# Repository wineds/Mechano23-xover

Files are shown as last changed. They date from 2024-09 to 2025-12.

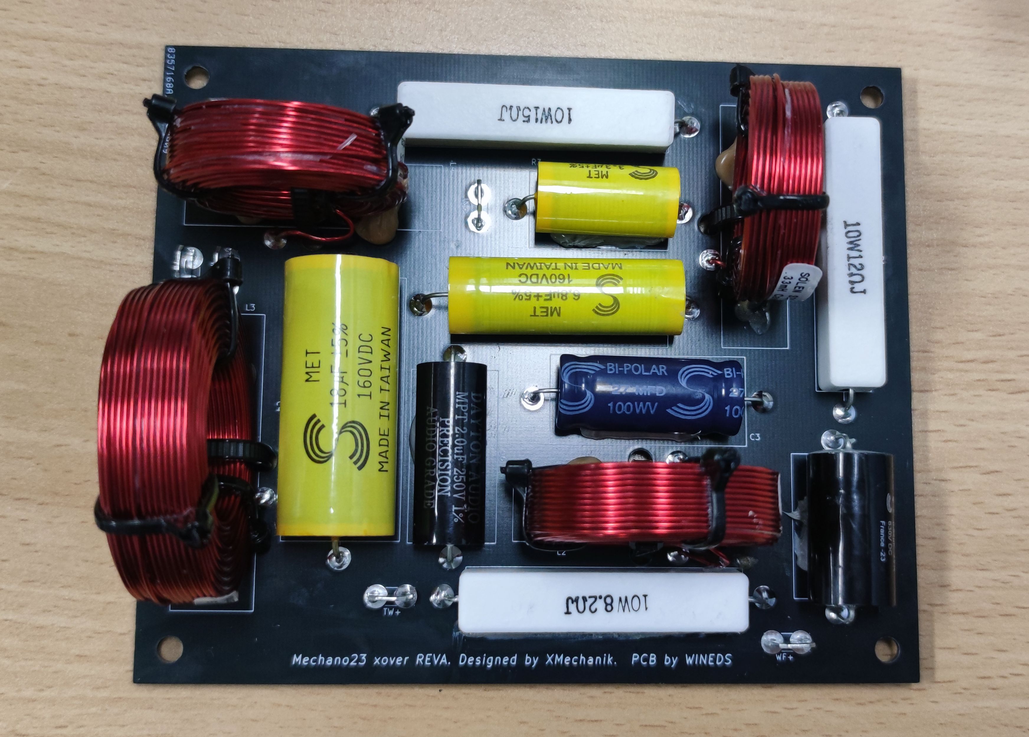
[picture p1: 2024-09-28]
1726199938259.jpg

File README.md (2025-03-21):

Manufacturing files for Mechano23 xover PCB.  The RAR file needs to be uploaded to the PCB vendor (eg: JLCPCB or PCBWAY etc).

How to order from JLCPCB :

https://jlcpcb.com/help/article/How-do-I-place-an-order

NB : Use the "Add Gerber files" button to upload (mechano23_revA_plots.rar) RAR file.

BOM is as per component links in the first post of the ASR review here : https://www.audiosciencereview.com/forum/index.php?threads/mechano23-open-source-diy-speaker-review.54066/

Alternatively see simple BOM here : mechano23_xover_schematic.xls

6.3mm PCB lugs are as per H2094.pdf from local electronics store (5mm pitch, 1.2mm pin)  These would fit : https://www.newark.com/ettinger/19-68-041/terminal-pc-quick-fit-1-1mm/dp/10AC9921 (1.1mm pin)

Closest mouser alternative I could find is : https://au.mouser.com/ProductDetail/TE-Connectivity-AMP/725964-2?qs=qCxwlXJ4fnwpPO7DZFi5oQ%3D%3D  Pins are 1.3mm in this case but should push into PCB holes with some gentle persuasion.  Could also try these : https://www.newark.com/multicomp-pro/pc250-836lt/terminal-tab-6-35mm-solder-uninsulated/dp/05R7934 (cheaper but also 1.3mm pin))

For inductors I used "Liquid Nails" and cable ties ("knot" on component side) to secure them to the PCB.  For all other parts a neutral cure silcone was used to ensure parts don't rattle and buzz on PCB.  Cable tie holes are 4mm.

PCB mounting holes are 4.3mm.  

**IMPORTANT - The inductor leads are coated with enamel.  You will need to scrape/sand the ends of the leads to remove the enamel before soldering.  A hobby knife and/or sandpaper can be used for this purpose.




mechano23_xover_schematic

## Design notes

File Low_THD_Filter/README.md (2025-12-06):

Low Distortion Filter for Mechano23.

The filter needs to be placed in series with the woofer (either positive or negative terminal).

PCB lugs are the same as crossover PCB.

low_THD_filter_PCB





If you use the dayton 0.13mH inductor remove the cable tie furthest from the termination point and carefully start removing outer windings until only 4 remain.  This will result in a 0.11mH inductor.  Complete by adding a few new cable ties to aid mechancial stability.  I also applied some "liquid nails" to help keep the windings in place. viz:





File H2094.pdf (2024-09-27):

## Accessory ／ PCB Terminal

P-850

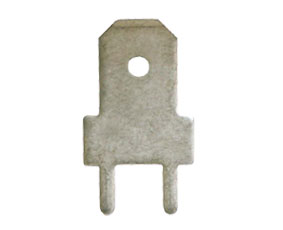
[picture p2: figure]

Material | Brass, Tin plated
Screw
Current Rating | 30A

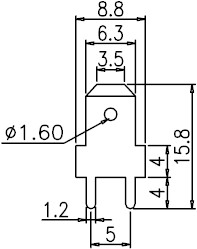
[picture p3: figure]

TEL: +886-2-2908-0614 | FAX: +886-2-2908-8549 | E-mail: infor@dinkle.com.tw

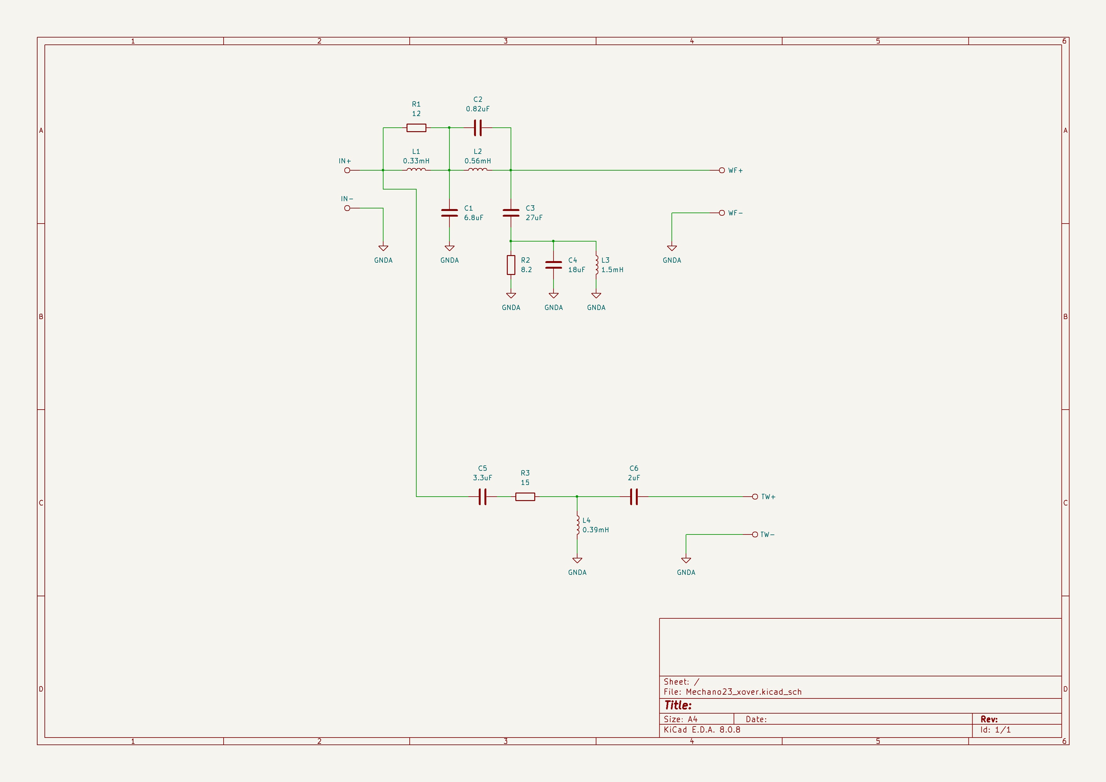
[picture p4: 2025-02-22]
mechano23_xover_schematic.jpg

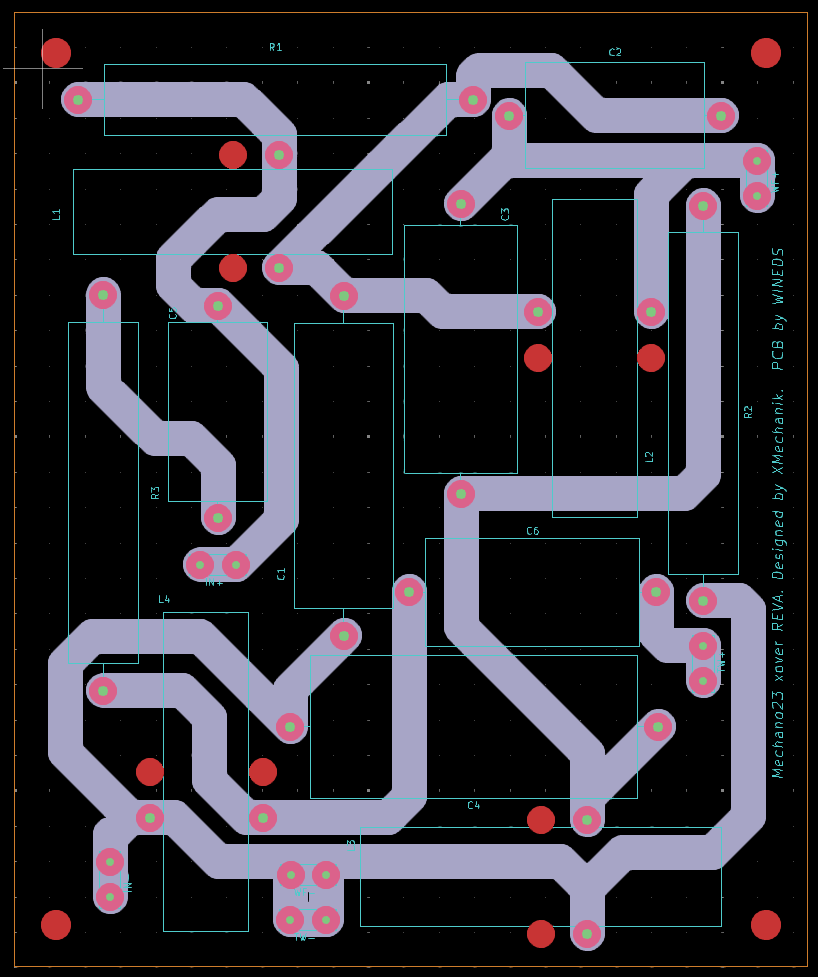
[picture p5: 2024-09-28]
Screenshot 2024-09-09 180137.png

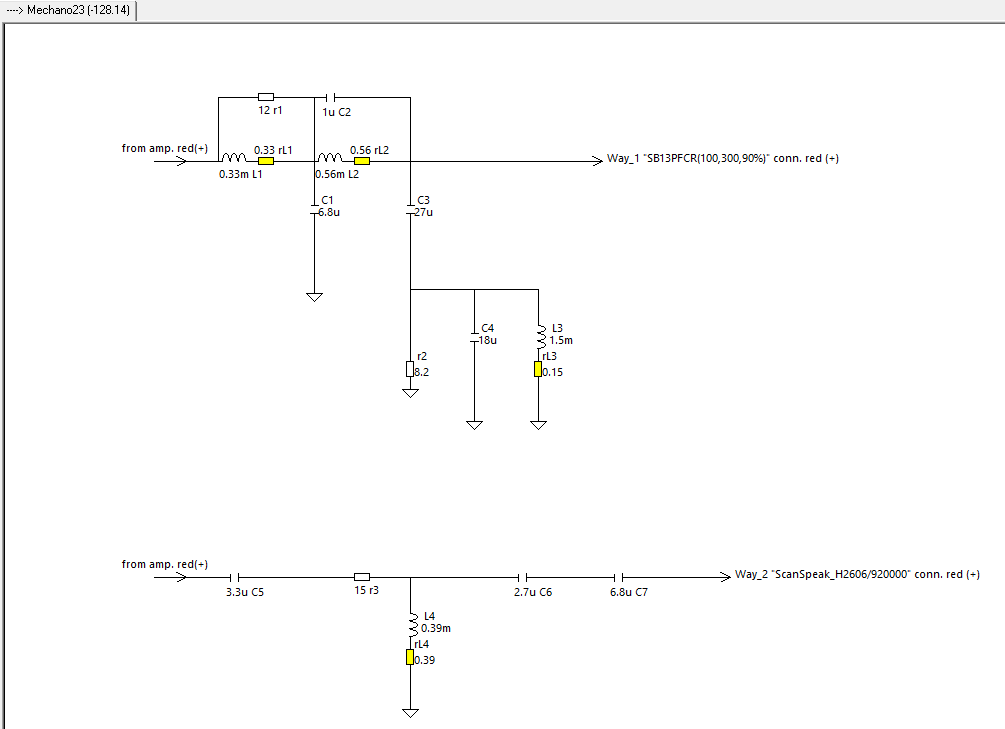
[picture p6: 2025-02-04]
schemat.png

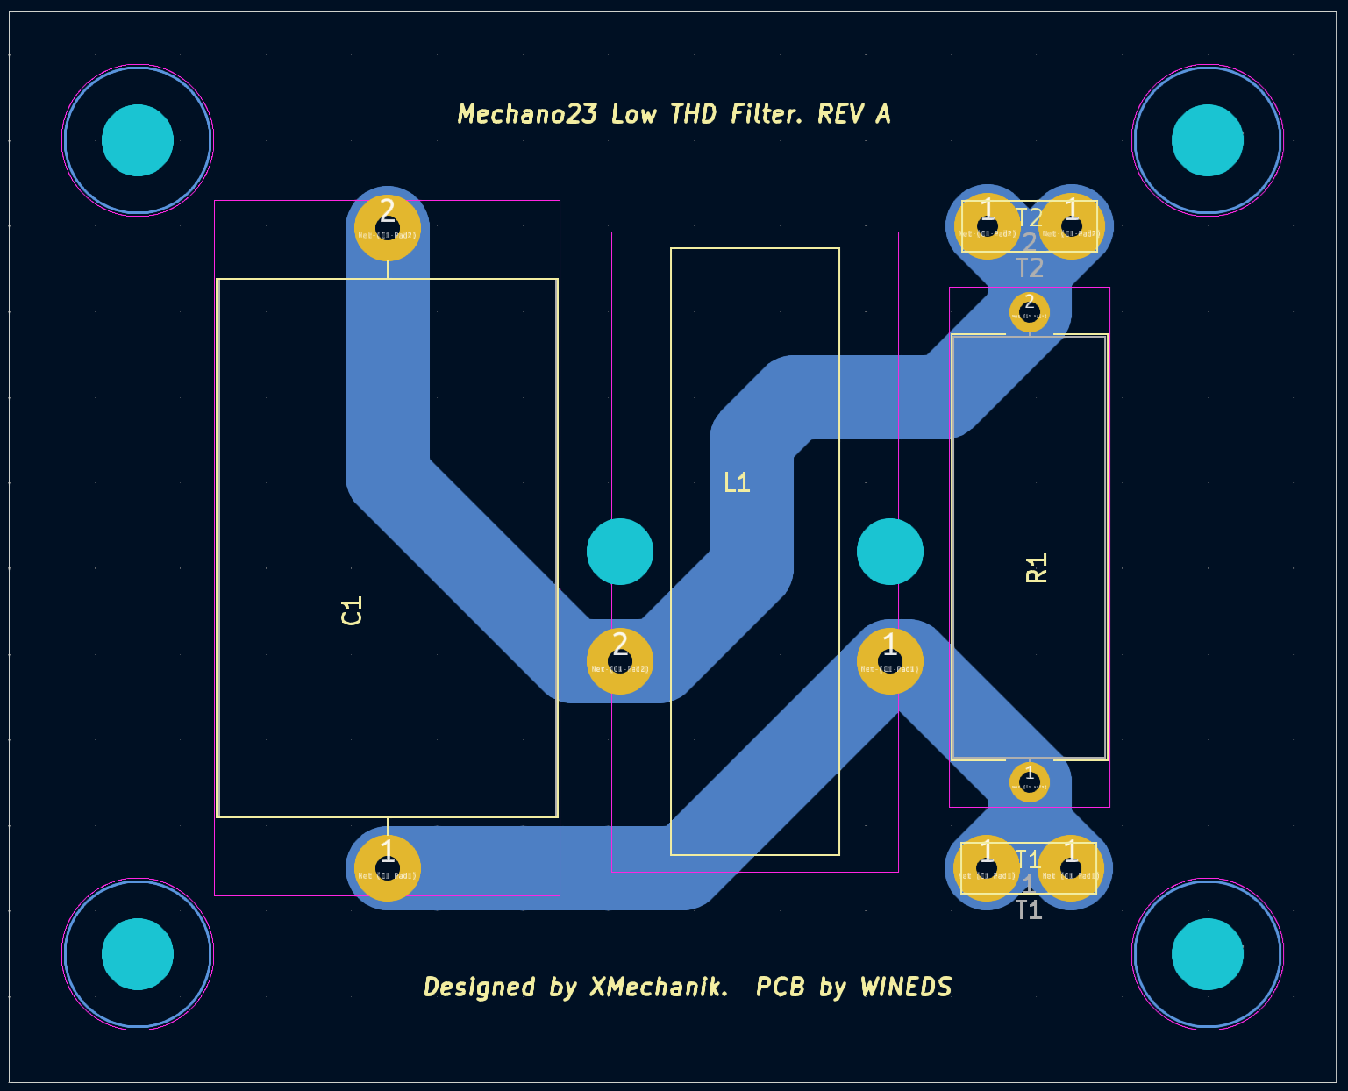
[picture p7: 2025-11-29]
Low_THD_Filter/low_THD_filter_PCB.png

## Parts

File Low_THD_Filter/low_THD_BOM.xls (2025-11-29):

Ref | Value | Supplier | Notes
L1 | 0.11mH | https://www.solen.ca/en/products/solen-perfect-lay-air-core-inductors-s18_11-0_11mh-18awg-inductor
 |  | https://jantzen-audio.com/?s=000-0266
 |  | https://www.daytonaudio.com/product/1320/lw18-13-0-13mh-18-awg-perfect-layer-inductor | Unwind all but 4 outer windings to make 0.11mH
C1 | 4.7uF | https://www.daytonaudio.com/product/187/pmpc-4-7-4-7uf-250v-precision-audio-capacitor
 | Optional see: | https://www.audiosciencereview.com/forum/index.php
R1 | 47ohm >=0.25w | https://jantzen-audio.com/?s=002-0364 | A generic metal film resistor >= 0.25W can also be used

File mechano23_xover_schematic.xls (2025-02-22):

Ref | Value | Supplier
L1 | 0.33mH | Ind. 0.33mH link CA$5.10 (https://www.solen.ca/en/products/solen-perfect-lay-air-core-inductors-s20_33-0_33mh-20awg-inductor)
L2 | 0.56mH | Ind. 0.56mH link CA$6.73 (https://www.solen.ca/en/products/solen-perfect-lay-air-core-inductors-s20_56-0_56mh-20awg-inductor)
L3 | 1.5mH | Ind. 1.5mH link CA$10.58 (https://www.solen.ca/en/products/solen-perfect-lay-air-core-inductors-s201_5-1_5mh-20awg-inductor)
L4 | 0.39mH | Ind. 0.39mH link CA$5.81 (https://www.solen.ca/en/products/solen-perfect-lay-air-core-inductors-s20_39-0_39mh-20awg-inductor)
R1 | 12ohm | Res. 12ohm link CA$0.41 (https://www.solen.ca/en/products/solen-cement-type-wirewound-resistors-wwsqp10j12r-12ohm-10watt-resistor)
R2 | 8.2ohm | Res. 8.2ohm link CA$0.41
R3 | 15ohm | Res. 15ohm link CA$0.41 (https://www.solen.ca/en/products/solen-cement-type-wirewound-resistors-wwsqp10j15r-15ohm-10watt-resistor)
C1 | 6.8uF | Cap. 6.8uF link CA$2.39 (https://www.solen.ca/en/products/solen-polyester-capacitors-pemt160j685-6_8uf-160v-metallized-polyester-film)
C2 | 0.82uF | Cap. 0.82uF link CA$6.09 (https://www.solen.ca/en/products/solen-fast-capacitors-ppe082-0_82uf-630v-metallized-polypropylene-film)
C3 | 27uF | Cap. 27uF link CA$1.73 (https://www.solen.ca/en/products/solen-non-polarized-electrolytic-capacitors-b05a100k276-27uf-100v)
C4 | 18uF | Cap. 18uF link CA$6.39 (https://www.solen.ca/en/products/solen-polyester-capacitors-pemt160j186-18uf-160v-metallized-polyester-film)
C5 | 3.3uF | Cap. 3.3uF link CA$1.41 (https://www.solen.ca/en/products/solen-polyester-capacitors-pemt160j335-3_3uf-160v-metallized-polyester-film)
C6 | 2uF | Cap. 2.0uF link CA$2.48 (https://www.solen.ca/en/products/dmpc-2-0)

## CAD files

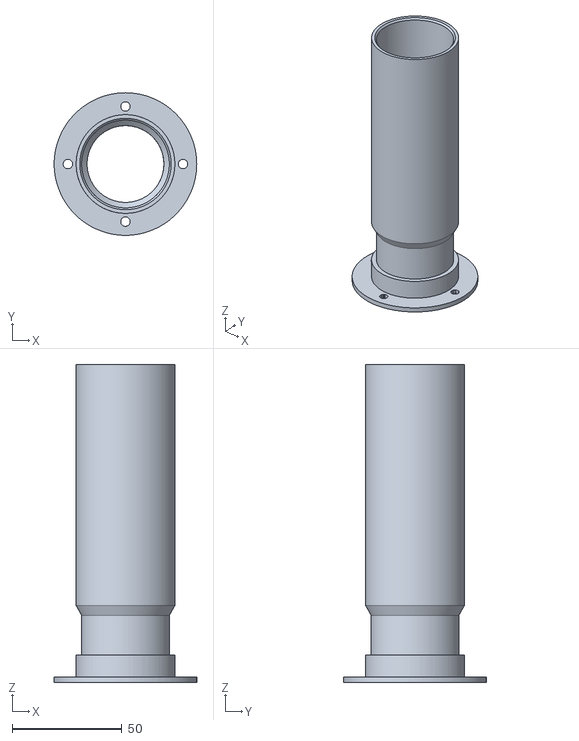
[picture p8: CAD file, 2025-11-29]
3D Printable port/Mechano23_port_rev6.stl
65.0 x 65.0 x 145.0

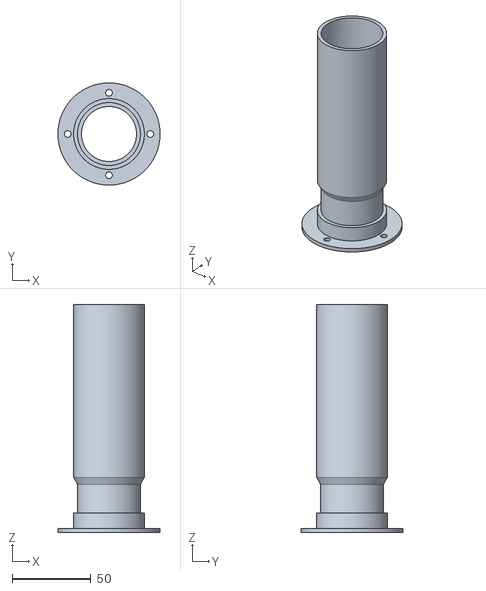
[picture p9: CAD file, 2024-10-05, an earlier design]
3D Printable port/Mechano23_port_rev4.stl
65.0 x 65.0 x 145.0

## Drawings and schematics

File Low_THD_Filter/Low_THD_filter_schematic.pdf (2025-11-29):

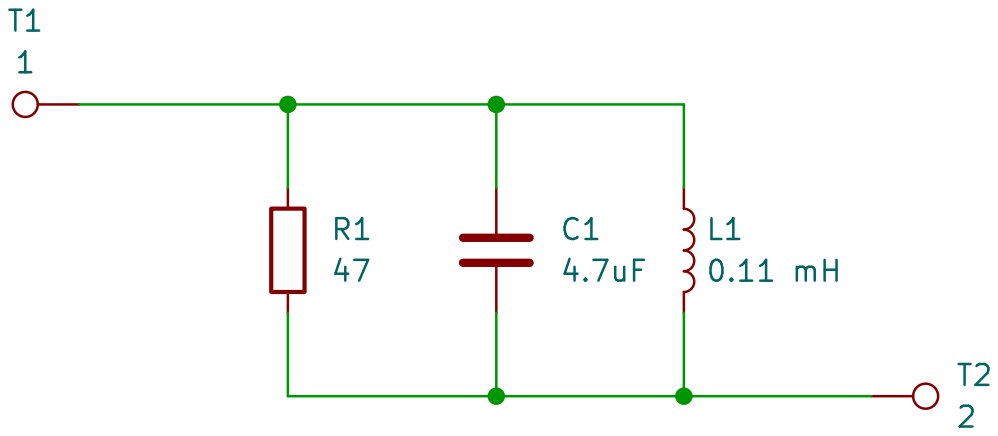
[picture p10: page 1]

Id: 1/1 Title: File: Low_THD_bass_trap.kicad_sch Sheet: / C1

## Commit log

2024-09-27 Create H2094.pdf
    datasheet for 6.3mm PCB lug
2025-02-04 Update README.md
    Added schematic of PCB
2025-02-22 Update README.md
    uploaded kicad sch
2025-02-22 Add files via upload
    Added BOM
    [mechano23_xover_schematic.xls]
